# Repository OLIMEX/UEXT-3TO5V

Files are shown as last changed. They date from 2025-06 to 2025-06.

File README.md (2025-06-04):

# UEXT-3TO5V
UEXT to UEXT converter from 3V host to 5V devices

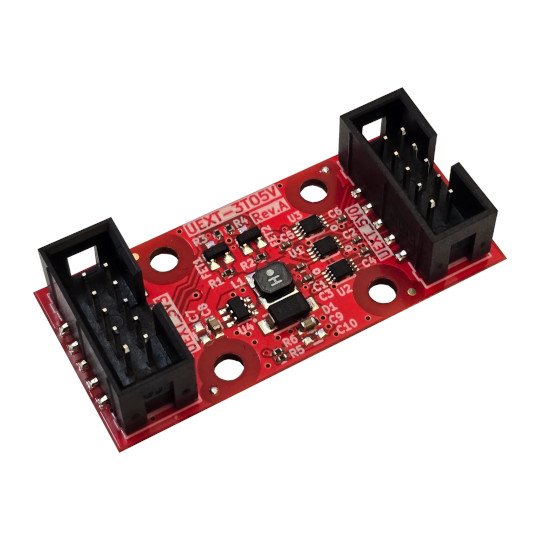
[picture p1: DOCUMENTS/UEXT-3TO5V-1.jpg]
UEXT-3TO5V-1


https://www.olimex.com/Products/Modules/Adapters/UEXT-3TO5V/open-source-hardware

## Licensee
* Hardware is released under CERN Open Hardware Licence Version 2 - Strongly Reciprocal
* Documentation is released under CC BY-SA 4.0

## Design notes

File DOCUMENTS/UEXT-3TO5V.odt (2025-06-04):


UEXT-3TO5V

User Manual

Rev.1.0 June 2025 olimex.com

# Introduction to UEXT-3TO5V

UEXT (https://www.olimex.com/Products/Modules/) standard is for 3.3V devices. This is natural as most of modern processors work on 3.3V.

Sometimes though is necessary to access sensors and devices which work on 5V. In this case we need level converters.

Also it’s nice to power these sensors and devices from the UEXT (https://www.olimex.com/Products/Modules/), so step up converter from 3 to 5V is also necessary.

UEXT-3TO5V (https://www.olimex.com/Products/Modules/Adapters/UEXT-3TO5V/open-source-hardware) solves these issues. It have step up converter which takes power from the 3V UEXT (https://www.olimex.com/Products/Modules/) connector and convert it to 5V.

Also all UEXT (https://www.olimex.com/Products/Modules/) signals UART, I2C, SPI have proper level shifters so these interfaces can be used on 5V devices.

Note that UEXT-3TO5V (https://www.olimex.com/Products/Modules/Adapters/UEXT-3TO5V/open-source-hardware) is not reversible i.e. can’t be used to access 3V devices from 5V UEXT (https://www.olimex.com/Products/Modules/) because of the step up converter it’s unidirectional and only produces 5V from 3.3V not vice versa!

The maximum current which the step up converter can produce is 1A (if the UEXT (https://www.olimex.com/Products/Modules/) 3.3V can provide enough current).

# Order codes for UEXT-3TO5V:

UEXT-3TO5V (https://www.olimex.com/Products/Modules/Adapters/UEXT-3TO5V/open-source-hardware) UEXT (https://www.olimex.com/Products/Modules/) converter from 3V to 5V with step up converter and level shifters

# HARDWARE

## UEXT-3TO5V layout

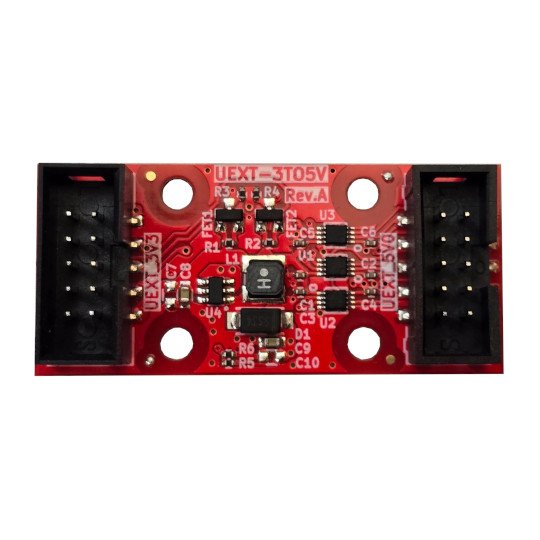
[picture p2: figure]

  UEXT 3.3V side UEXT 5V side 3V to 5V converter Level Shifters

## UEXT-3TO5V schematic:

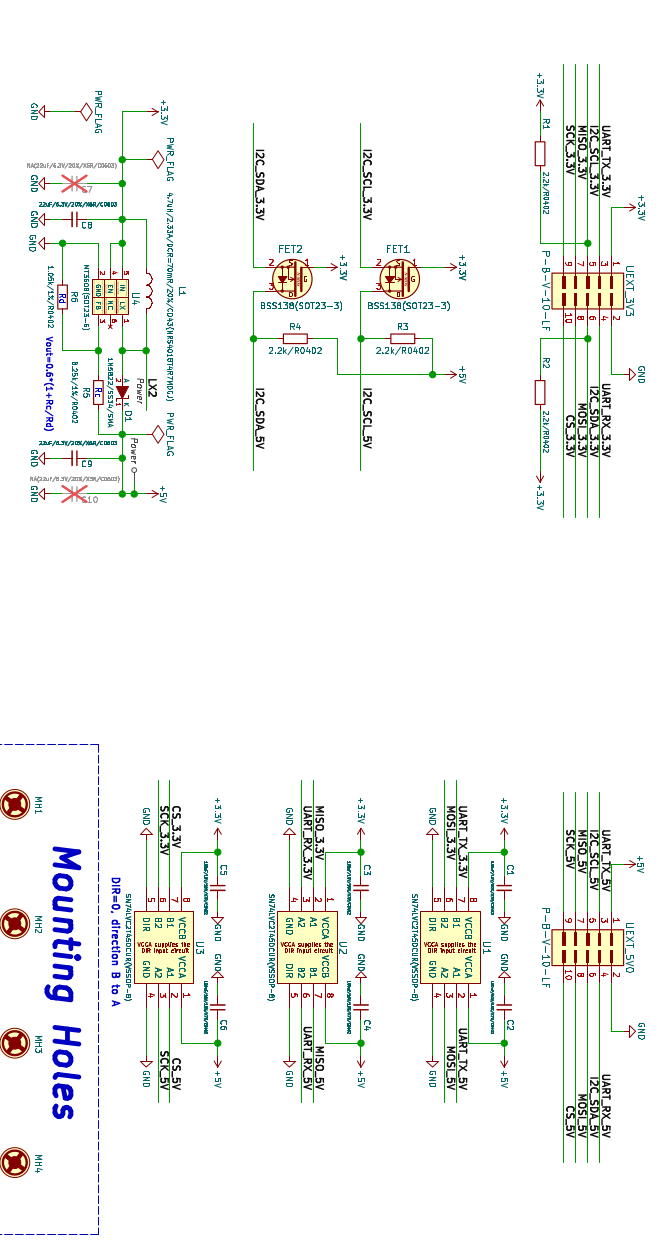
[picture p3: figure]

## UEXT connector signals:

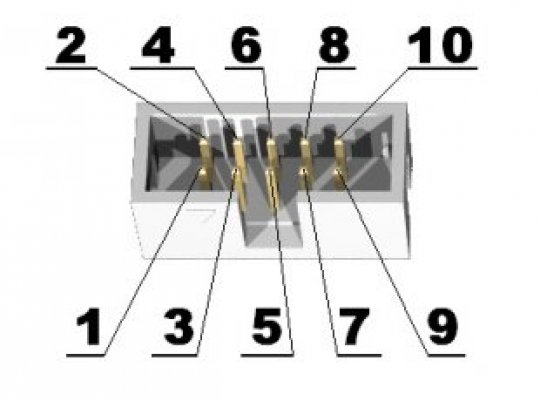
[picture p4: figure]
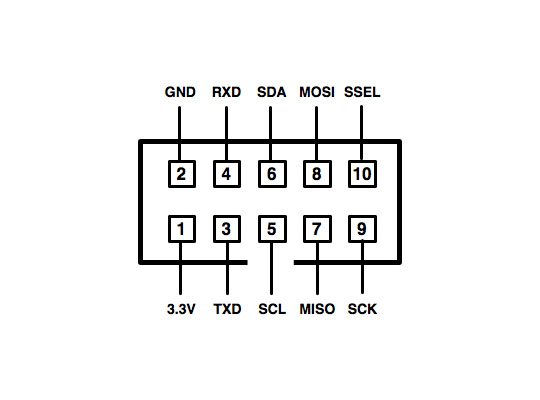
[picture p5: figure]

# Revision History

Revision 1.0 June 2025

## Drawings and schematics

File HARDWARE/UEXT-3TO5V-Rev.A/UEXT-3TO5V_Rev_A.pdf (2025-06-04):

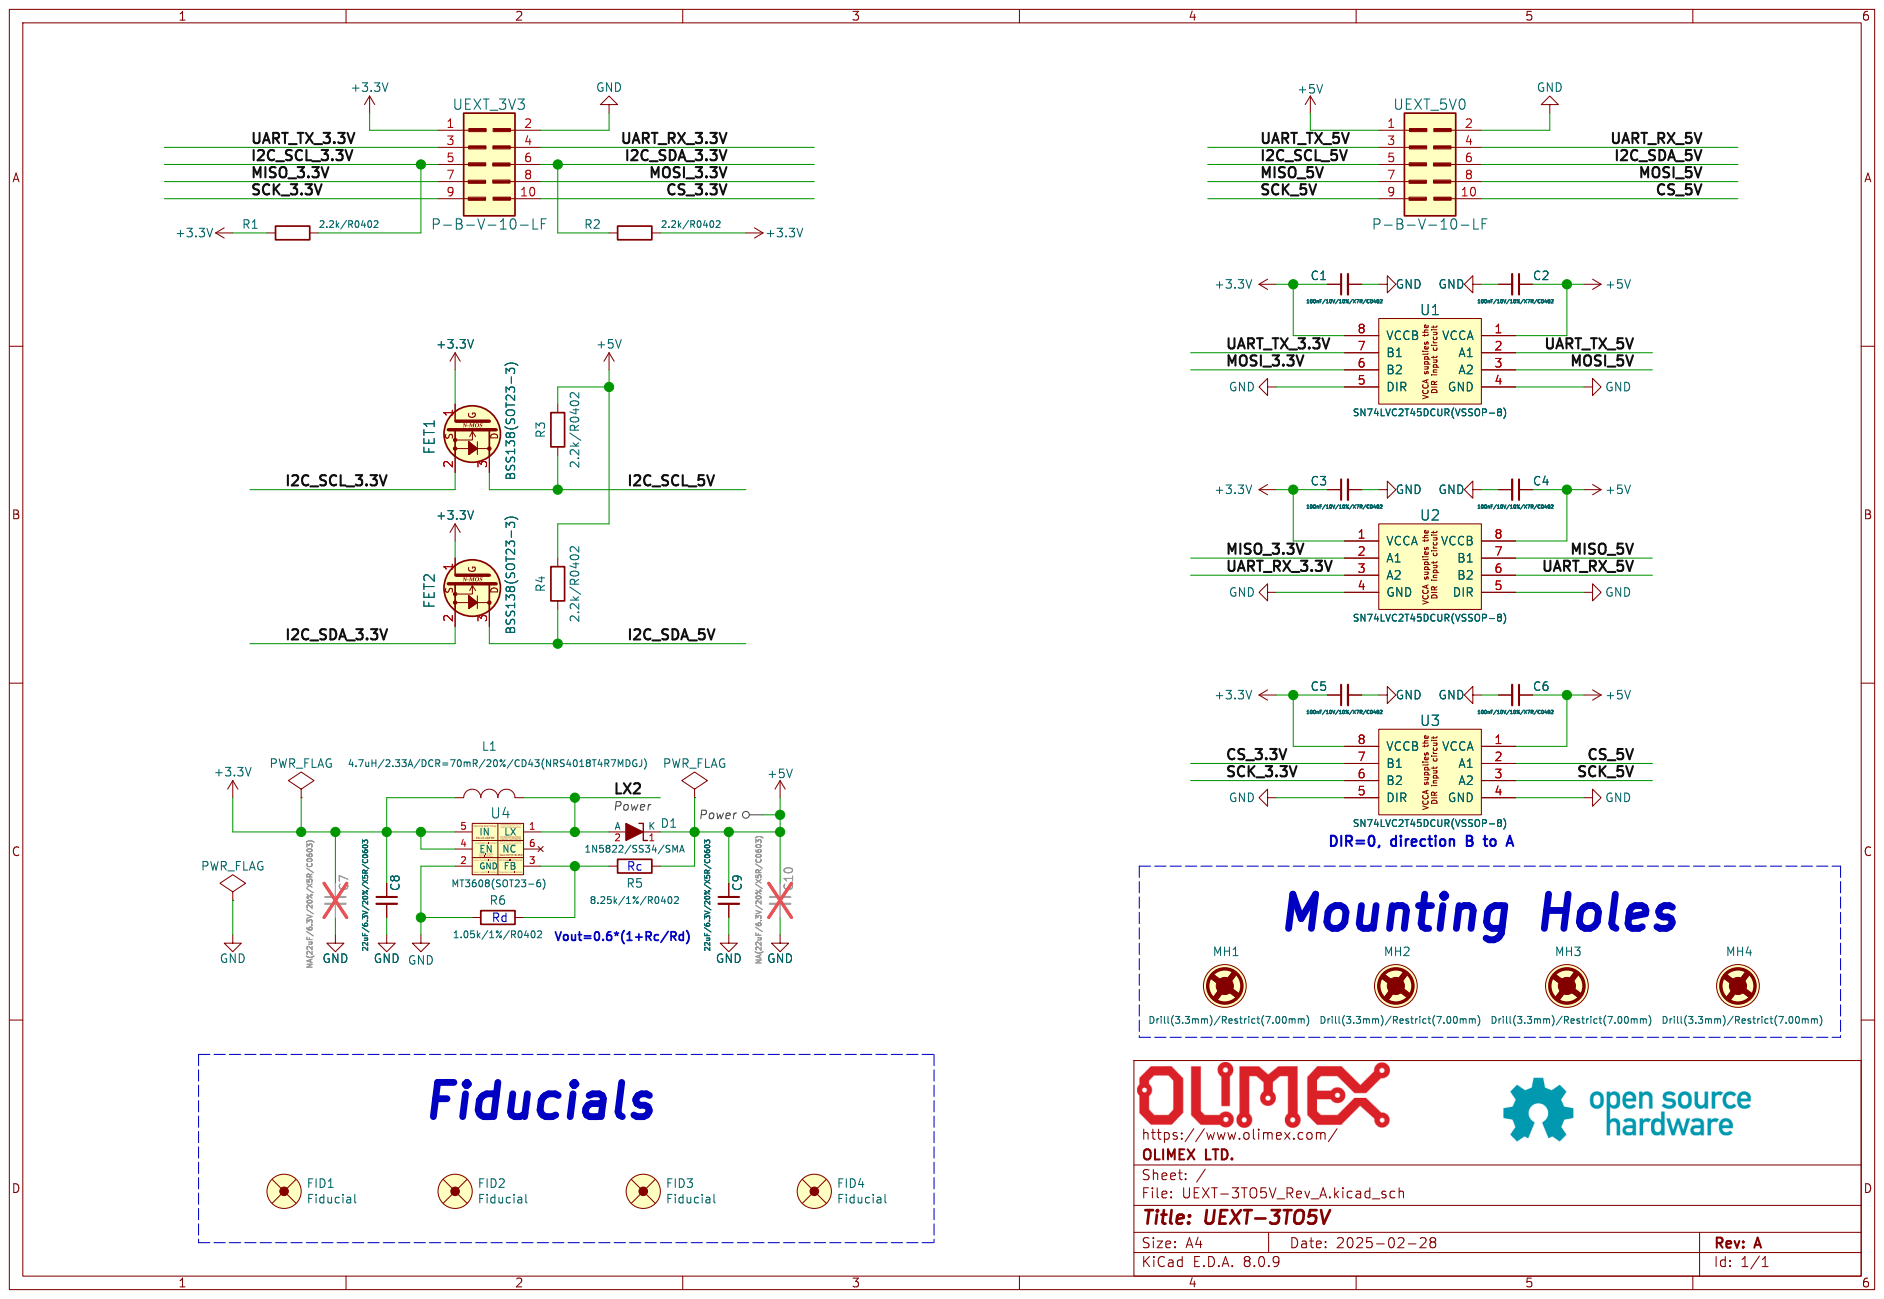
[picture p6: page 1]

Vout=0.6*(1+Rc/Rd) LX FB The inductorshouldhavelow corelossat 1.2MHz | 1 GND 2 3 EN 4 andlow DCR for betterefficiency. RecommendedInput/OutputCapacitors: 22uF/X5R(X7R). Schottkydiodeis a goodchoicefor MT3608

QuiescentCurrent(PFM)=200uA(Max) QuiescentCurrent(PWM)=2.2mA(Max) RecommendedInductorvalues:up to 22uH. Current(Shutdown)=1uA(Max) V(ENL)=0.4V(Max) Vin=(2-24)VDC | FB InputBiasCurrent=-50nA(min) FB Voltage=0.6V(Typical) OperatingInputVoltage because of its low forwardvoltagedropandfast reversesrecovery. V(ENH)=1.5V(Min)

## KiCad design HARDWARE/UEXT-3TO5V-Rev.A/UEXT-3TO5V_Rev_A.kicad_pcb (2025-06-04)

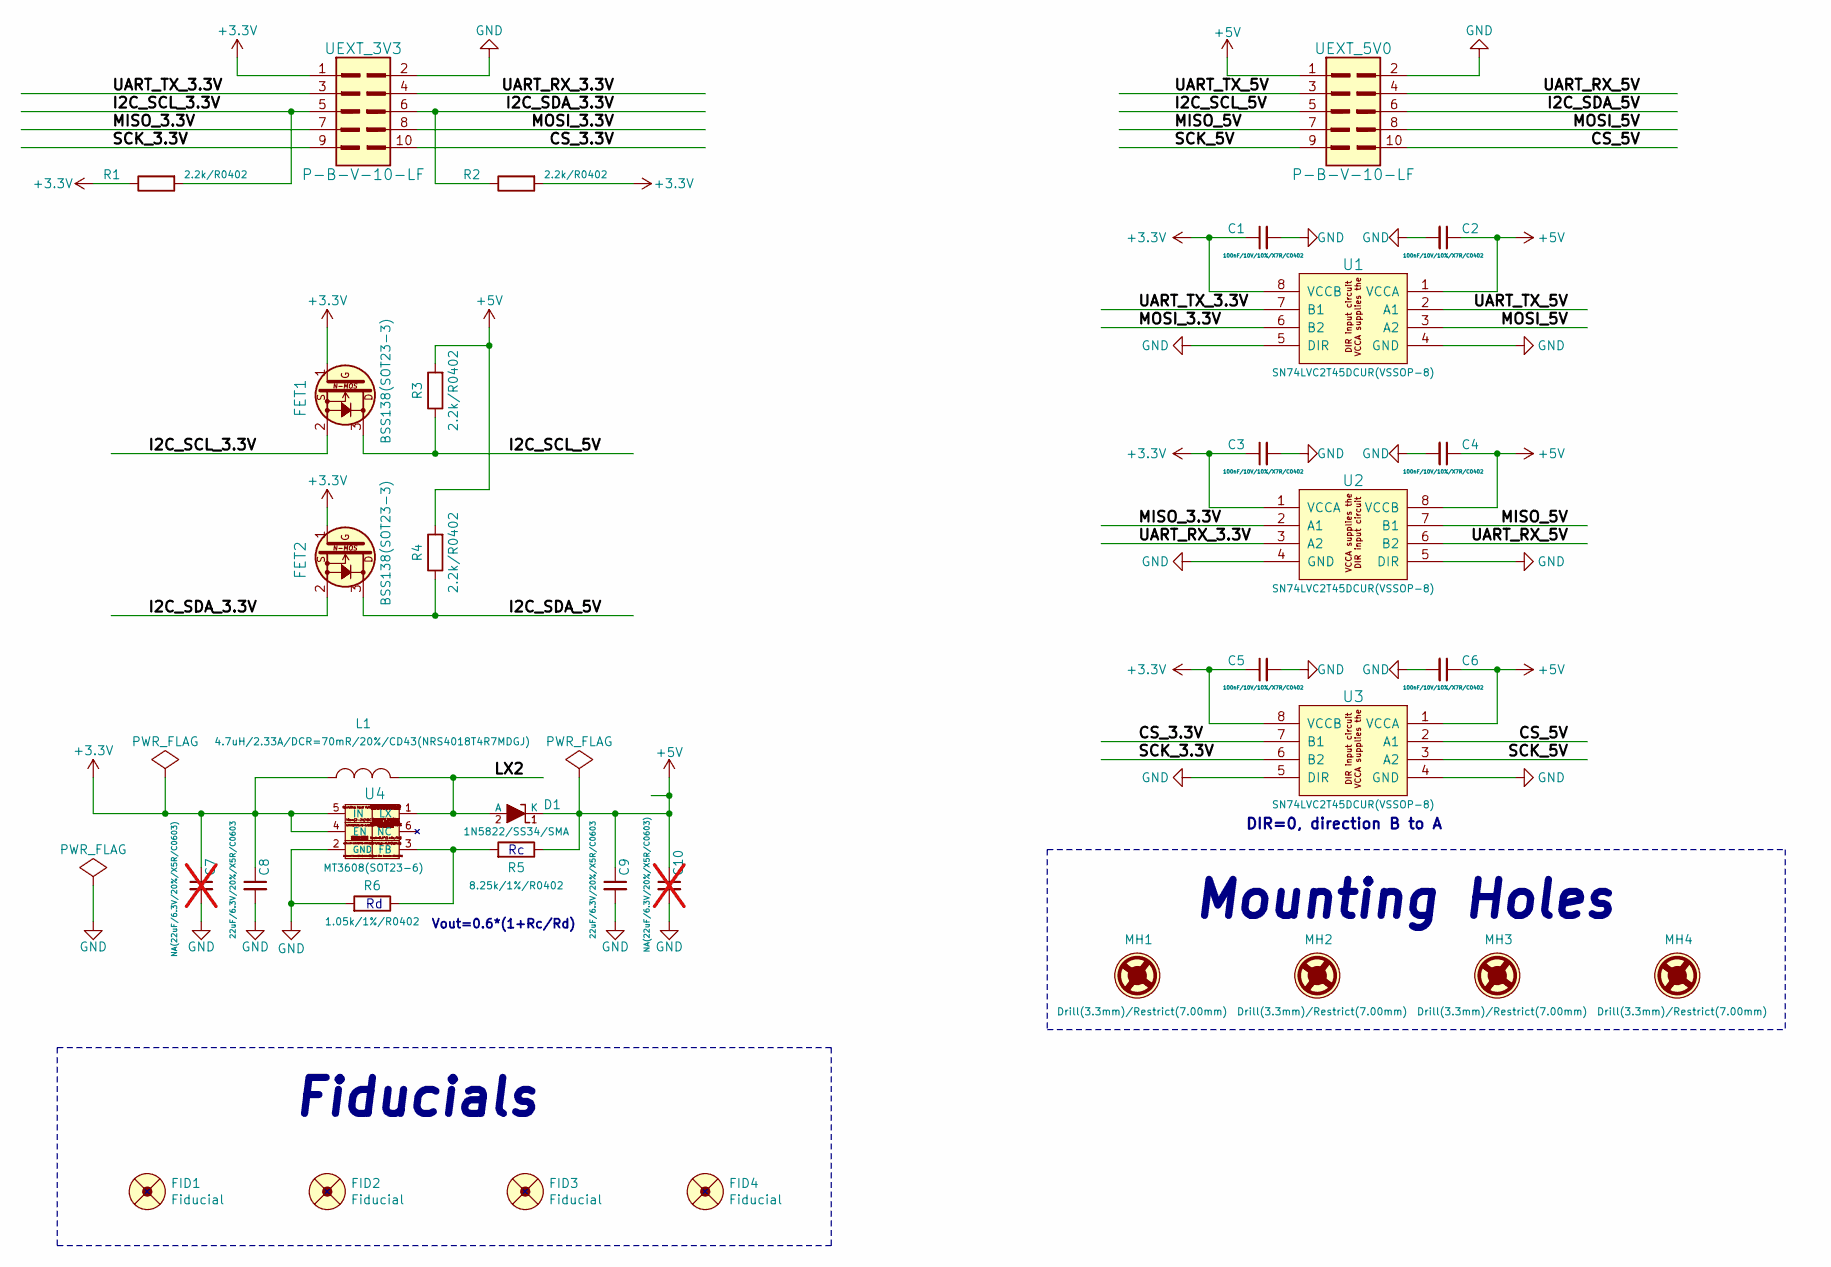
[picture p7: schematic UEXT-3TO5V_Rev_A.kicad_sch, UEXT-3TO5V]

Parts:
C1, C2, C3, C4, C5, C6: 100nF/10V/10%/X7R/C0402; C_0402_5MIL_DWS
C7, C10: NA(22uF/6.3V/20%/X5R/C0603); C_0603_5MIL_DWS; not fitted
C8, C9: 22uF/6.3V/20%/X5R/C0603; C_0603_5MIL_DWS
D1: 1N5822/SS34/SMA; SMA-KA
FET1, FET2: BSS138(SOT23-3); SOT23
FID1, FID3: Fiducial; Fiducial1x3
FID2, FID4: Fiducial; Fiducial1x3_Paste
L1: 4.7uH/2.33A/DCR=70mR/20%/CD43(NRS4018T4R7MDGJ); CD42(43)
MH1, MH2, MH3, MH4: Drill(3.3mm)/Restrict(7.00mm); Mounting_Hole_Drill-3.3mm_Clerance-7mm
R1, R2, R3, R4: 2.2k/R0402; R_0402_5MIL_DWS
R5: 8.25k/1%/R0402; R_0402_5MIL_DWS
R6: 1.05k/1%/R0402; R_0402_5MIL_DWS
U1, U2, U3: SN74LVC2T45DCUR(VSSOP-8); VSSOP-8_Pitch-0.50mm_Pad-0.25mm_Dimensions-2.30x2.00x1.00mm
U4: MT3608(SOT23-6); SOT23-6
UEXT_3V3, UEXT_5V0: P-B-V-10-LF; GBH-254-SMT-10

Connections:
+3.3V: C1.1, C3.1, C5.1, C7.1, C8.1, FET1.1 (G), FET2.1 (G), L1.2, R1.1, R2.2, U1.8 (VCCB), U2.1 (VCCA), U3.8 (VCCB), U4.4 (EN), U4.5 (IN), UEXT_3V3.1
+5V: C2.1, C4.1, C6.1, C9.1, C10.1, D1.1 (K), R3.2, R4.2, R5.1, U1.1 (VCCA), U2.8 (VCCB), U3.1 (VCCA), UEXT_5V0.1
/CS_3.3V: U3.7 (B1), UEXT_3V3.10
/CS_5V: U3.2 (A1), UEXT_5V0.10
/I2C_SCL_3.3V: FET1.2 (S), R1.2, UEXT_3V3.5
/I2C_SCL_5V: FET1.3 (D), R3.1, UEXT_5V0.5
/I2C_SDA_3.3V: FET2.2 (S), R2.1, UEXT_3V3.6
/I2C_SDA_5V: FET2.3 (D), R4.1, UEXT_5V0.6
/LX2: D1.2 (A), L1.1, U4.1 (LX)
/MISO_3.3V: U2.2 (A1), UEXT_3V3.7
/MISO_5V: U2.7 (B1), UEXT_5V0.7
/MOSI_3.3V: U1.6 (B2), UEXT_3V3.8
/MOSI_5V: U1.3 (A2), UEXT_5V0.8
/SCK_3.3V: U3.6 (B2), UEXT_3V3.9
/SCK_5V: U3.3 (A2), UEXT_5V0.9
/UART_RX_3.3V: U2.3 (A2), UEXT_3V3.4
/UART_RX_5V: U2.6 (B2), UEXT_5V0.4
/UART_TX_3.3V: U1.7 (B1), UEXT_3V3.3
/UART_TX_5V: U1.2 (A1), UEXT_5V0.3
GND: C1.2, C2.2, C3.2, C4.2, C5.2, C6.2, C7.2, C8.2, C9.2, C10.2, R6.2, U1.4 (GND), U1.5 (DIR), U2.4 (GND), U2.5 (DIR), U3.4 (GND), U3.5 (DIR), U4.2 (GND), UEXT_3V3.2, UEXT_5V0.2
unnamed: R5.2, R6.1, U4.3 (FB)

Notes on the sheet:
DIR=0, direction B to A
Mounting Holes
Fiducials
Vout=0.6*(1+Rc/Rd)

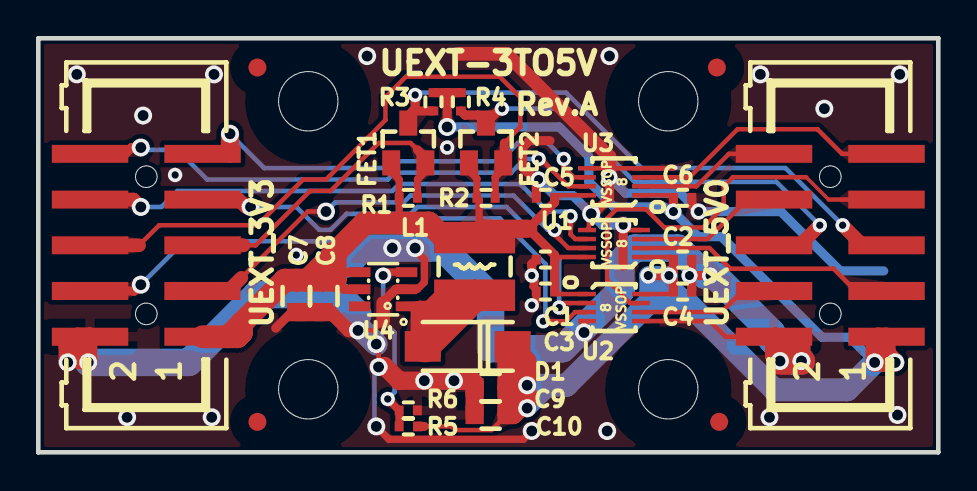
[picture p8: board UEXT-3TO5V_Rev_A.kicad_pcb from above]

Board: 2 copper layers, 50.0 x 23.0 mm, 41 parts (7 on the bottom side), 21 nets.

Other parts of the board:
Logo_OLIMEX_TB-Top: Logo_OLIMEX_TB
Sign_Antistatic: Sign_Antistatic
Sign_CE: CE_Sign
Sign_OSHW_8x8: Sign_OSHW_8x8
Sign_PB-Free: Sign_PB-Free
Sign_RecycleBin: Sign_RecycleBin; Sign_RecycleBin_1
Sign_RoHS: Sign_RoHS; Sign_RoHS_1

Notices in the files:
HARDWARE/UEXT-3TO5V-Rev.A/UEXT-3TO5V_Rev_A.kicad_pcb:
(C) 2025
